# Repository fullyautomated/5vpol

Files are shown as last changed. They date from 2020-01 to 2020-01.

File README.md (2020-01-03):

# 16-V Input 3-A Output Point-of-Load with TPS62135

## Overview

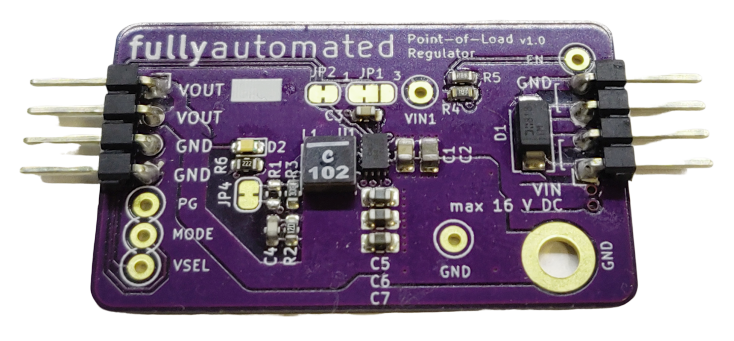
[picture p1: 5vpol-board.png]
Photo of the Fully Automated 17-V PoL


This design is based around the Texas Instruments TPS62135 converter.  
[IC Datasheet](/tps62135.pdf). [Board Schematic](/5vpol_color.pdf).  
For layout, see the .kicad_pcb file in the repository.

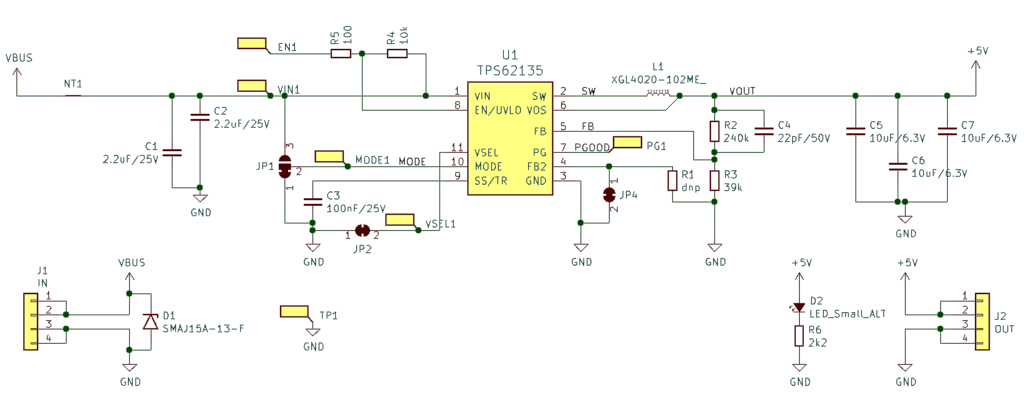
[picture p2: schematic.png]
Schematic of the board.


## Use

Connect the input side to the power source, and the output side to the load. The converter powers on automatically above 3V input. Output is programmed to 5.0 volt, can be changed by replacing R2 and/or R3. Reference voltage is 0.7 V. Supported input voltage is around 16 V max., above which the D1 TVS diode will start to clamp. You can remove this to increase maximum input voltage to 18V abs max, but then you should avoid hot-plugging the board.

You can shut down the converter while input power is present: Pull EN input low. The EN pin is pulled up on-board to VIN with 10kOhm, therefore the circuit you use to discharge EN must withstand the maximum VIN you plan to apply.

Alternatively, you can disconnect the input.

To achieve 20-ish uA standby current, remove the output indicator LED D2 or its series resistor R6.

This DC/DC can run in 100% duty cycle mode, when the input voltage is lower or equals to the set output voltage.

## Properties

| Specifications | |
|---:|---|
| Dimensions: | 25x42x3mm (without pin headers) |
| Mass: | 3.3g |
| Mounting Hole: | M3 at (-6;-4)mm from bottom right corner |
| Input Voltage: | 3V - 16V |
| Output Voltage: | 5.0V (default)<br>Optionally between 0.8V and 12V |
| Internal Reference Voltage: | 0.7V |
| Output Ripple: | 45mVpp with no load<br>30mVpp in Continuous Conduction Mode |
| Output Current: | 4A peak<br>3.4A continuous |
| Maximum Duty Cylce: | 100% |
| Power Stage: | Synchronous buck with nMOS switches |
| Overtemperature Protection: | Yes, at 160 degrees Celsius, with 20 dC hysteresis |
| Short Circuit Protection: | Yes, at 6A |
| Fixed Switching Frequency: | No. (default) In Continuous Conduction Mode fSW is approx. 2.5 MHz <br> Yes (pseudo-static around 2.5 MHz) by pulling MODE pin high (VIN tolerant) |
| Soft Start: | 25ms, programmed by C3 |
| Transient Input Overvoltage Protection: | Yes, with on-board TVS diode |
| Output Overvoltage Protection: | No. |
| Hot-Plug Capable: | Yes. |
| Soft Shutdown: | Yes (by pulling EN pin low) |
| Output ON Indicator: | Yes. (pink LED) |
| Power Good Output: | Yes. |
| RoHS: | Yes, plus tantalum-free. |

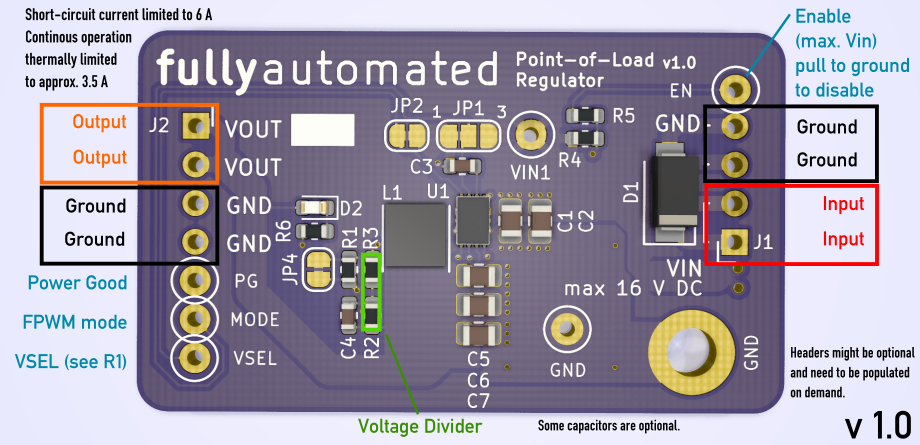
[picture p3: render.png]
Render of the board with pins labeled


## Test report

I spent half a year validating this IC design before it was released to the market, and it is very robust. The only way to kill it is through overvoltage on its input or its output (or maybe using the wrong inductor and saturating it, but I have not tried that; it still works down to 0.7 uH).

Current limit is robust, and it also limits negative current when run in FPWM mode (MODE=high, see JP1) to around 1A. You can use it as a rudimentary bidirectional buck-boost if you so please!

You can even use it as an inverting buck-boost converter! (connect GND to the pin labeled VOUT, VIN is VIN, GND is -Vout) Mind that in this setup Vin+abs(Vout) still can't be higher than 17V!

Well designed, lovely IC, would recommend it anytime. Thanks Konrad and Hongcheng.

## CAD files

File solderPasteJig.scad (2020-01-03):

pcb = [42.1,25.13,1.6];
gap = 0.1;

base = [120, 120, 0.2];

module jig() {
    difference() {
        union() {
            translate([0, 0, (base.z+pcb.z)/2])
                cube(base + [0,0, pcb.z], center=true);
        }
        union() {
            translate([0, 0, base.z+pcb.z/2+0.01])
                cube(pcb+[1,1,0]*gap, center=true);
            
            for(i=[0:2])
                translate([(i-1)*pcb.x/4,0,-1])
                    cylinder(d=4, h=pcb.z+base.z+2);
        }
    }
}

jig();

module shim() {
    difference() {
        cube([41, 24, 0.8], center=true);
        translate([-27,0,-1])
            rotate([0,0,45])
                cube([100,100,100]);
    }
}

$fn = 64;

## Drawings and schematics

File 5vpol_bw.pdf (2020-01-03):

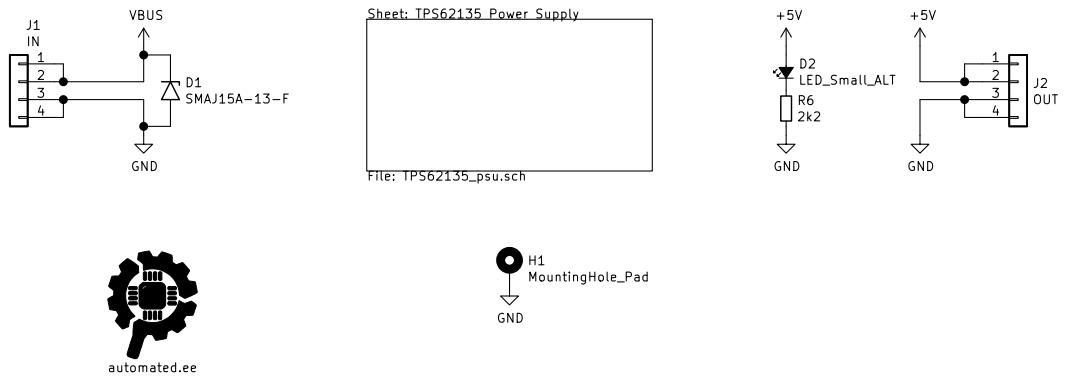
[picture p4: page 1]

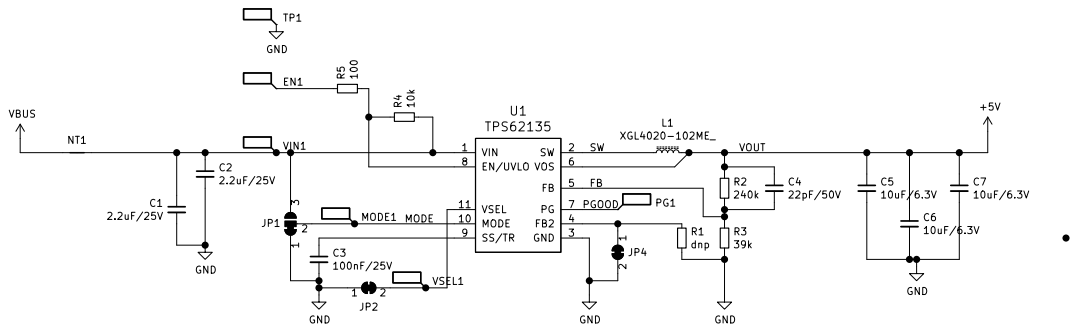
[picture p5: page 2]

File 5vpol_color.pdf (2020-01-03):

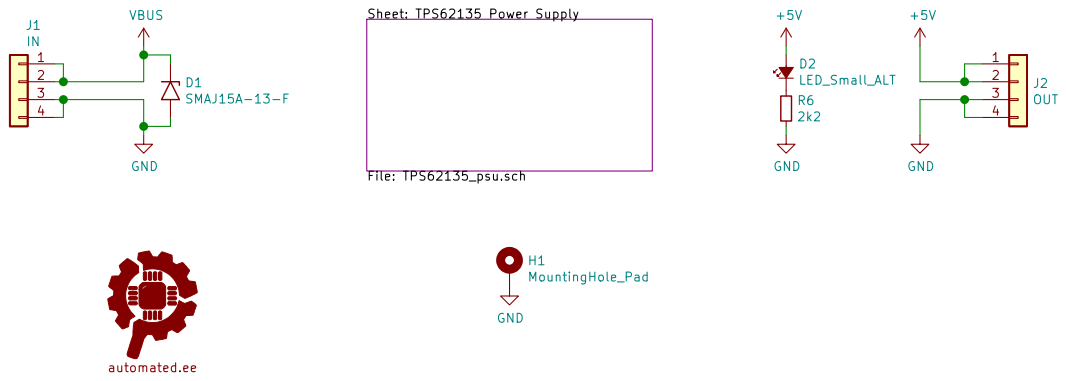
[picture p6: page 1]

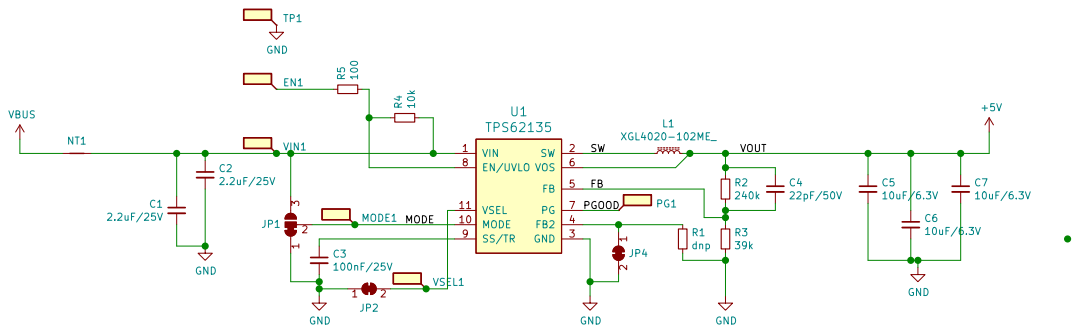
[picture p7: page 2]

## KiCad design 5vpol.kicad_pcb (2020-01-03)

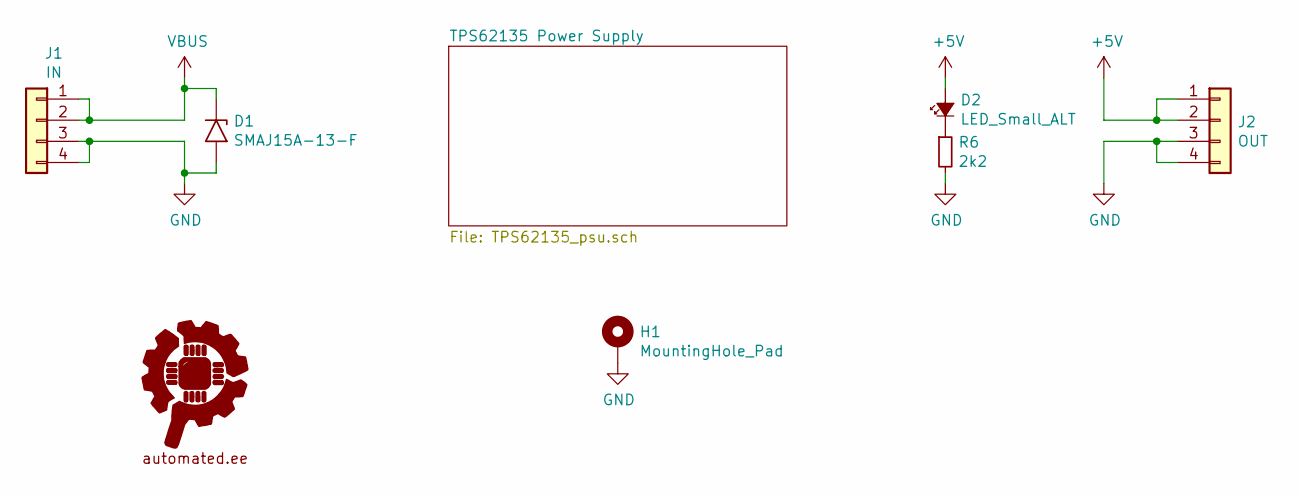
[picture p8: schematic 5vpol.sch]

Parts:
D1: SMAJ15A-13-F; D_SMA
D2: LED_Small_ALT; LED_0603_1608Metric
G1: Fully_Automated_Logo; fully_automated_logo_soldermask
H1: MountingHole_Pad; MountingHole_3.2mm_M3_DIN965_Pad
J1: IN; PinSocket_1x04_P2.54mm_Horizontal
J2: OUT; PinSocket_1x04_P2.54mm_Horizontal
R6: 2k2; R_0603_1608Metric

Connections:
+5V: D2.2 (A), J2.1, J2.2; also elsewhere on the board
GND: D1.2 (A2), H1.1, J1.3, J1.4, J2.3, J2.4, R6.2; also elsewhere on the board
unnamed: D2.1 (K), R6.1
VBUS: D1.1 (A1), J1.1, J1.2; also elsewhere on the board

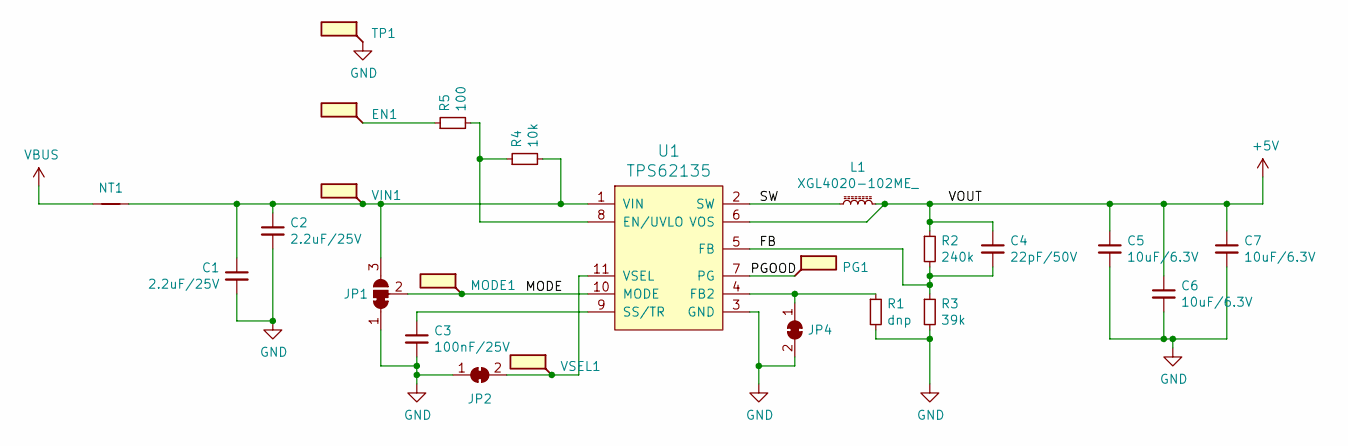
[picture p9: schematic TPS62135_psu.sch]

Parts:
C1, C2: 2.2uF/25V; C_0805_2012Metric
C3: 100nF/25V; C_0603_1608Metric
C4: 22pF/50V; C_0603_1608Metric
C5, C6, C7: 10uF/6.3V; C_0805_2012Metric
EN1: EN; TestPoint_Loop_D1.80mm_Drill1.0mm_Beaded
JP1: SolderJumper_3_Bridged12; SolderJumper-3_P1.3mm_Bridged12_RoundedPad1.0x1.5mm_NumberL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
JP2, JP4: SolderJumper_2_Bridged; SolderJumper-2_P1.3mm_Bridged_RoundedPad1.0x1.5mm
L1: XGL4020-102ME_; L_Coilcraft_XxL4020
MODE1: MODE; TestPoint_Loop_D1.80mm_Drill1.0mm_Beaded
NT1: Net-Tie_2; NetTie-2_SMD_Pad2.0mm
PG1: PG; TestPoint_Loop_D1.80mm_Drill1.0mm_Beaded
R1: dnp; R_0603_1608Metric
R2: 240k; R_0603_1608Metric
R3: 39k; R_0603_1608Metric
R4: 10k; R_0603_1608Metric
R5: 100; R_0603_1608Metric
TP1: GND; TestPoint_Loop_D1.80mm_Drill1.0mm_Beaded
U1: TPS62135; RGX_TI_VQFN-HR11
VIN1: VIN; TestPoint_Loop_D1.80mm_Drill1.0mm_Beaded
VSEL1: VSEL; TestPoint_Loop_D1.80mm_Drill1.0mm_Beaded

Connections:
+5V: C4.1, C5.1, C6.1, C7.1, L1.2, R2.1, U1.6 (VOS); also elsewhere on the board
/TPS62135 Power Supply/FB: C4.2, R2.2, R3.1, U1.5 (FB)
/TPS62135 Power Supply/MODE: JP1.2 (C), MODE1.1, U1.10 (MODE)
/TPS62135 Power Supply/PGOOD: PG1.1, U1.7 (PG)
/TPS62135 Power Supply/SW: L1.1, U1.2 (SW)
GND: C1.2, C2.2, C3.2, C5.2, C6.2, C7.2, JP1.1 (A), JP2.1 (A), JP4.2 (B), R1.2, R3.2, TP1.1, U1.3 (GND); also elsewhere on the board
unnamed: C1.1, C2.1, JP1.3 (B), NT1.2, R4.2, U1.1 (VIN), VIN1.1
unnamed: C3.1, U1.9 (SS/TR)
unnamed 9: EN1.1, R5.1; also elsewhere on the board
unnamed: JP2.2 (B), U1.11 (VSEL), VSEL1.1
unnamed: JP4.1 (A), R1.1, U1.4 (FB2)
unnamed: R4.1, R5.2, U1.8 (EN/UVLO)
VBUS: NT1.1; also elsewhere on the board

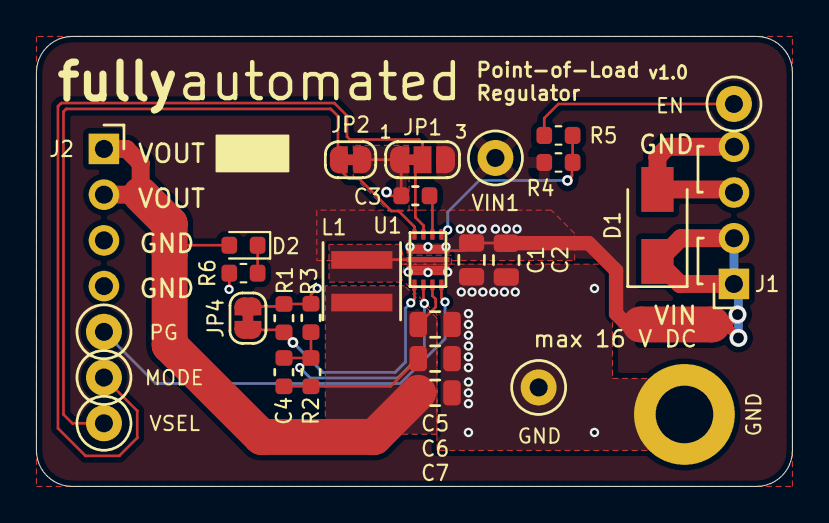
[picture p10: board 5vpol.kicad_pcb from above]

Board: 2 copper layers, 42.0 x 25.0 mm, 31 parts (1 on the bottom side), 14 nets.

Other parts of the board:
EN: EN; TestPoint_Loop_D1.80mm_Drill1.0mm_Beaded

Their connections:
unnamed 9: EN.1; also elsewhere on the board

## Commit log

2020-01-03 version 1.0
    [5vpol.kicad_pcb, 5vpol.sch, TPS62135_psu.sch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]
2020-01-03 fixed reference voltage error
